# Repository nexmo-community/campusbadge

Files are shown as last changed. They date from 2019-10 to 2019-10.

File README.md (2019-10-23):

# Vonage Campus Developer Conference Badge

Welcome to [Vonage Campus](https://www.vonage.com/campus/)! This repo is dedicated to the software for the Developer Track Conference Badges.

We love all things [#badgelife](https://hackaday.com/tag/badgelife/) and we thought our attendees might enjoy this too :)

Badge owners: check the [wiki](https://github.com/nexmo-community/campusbadge/wiki) for all the information.

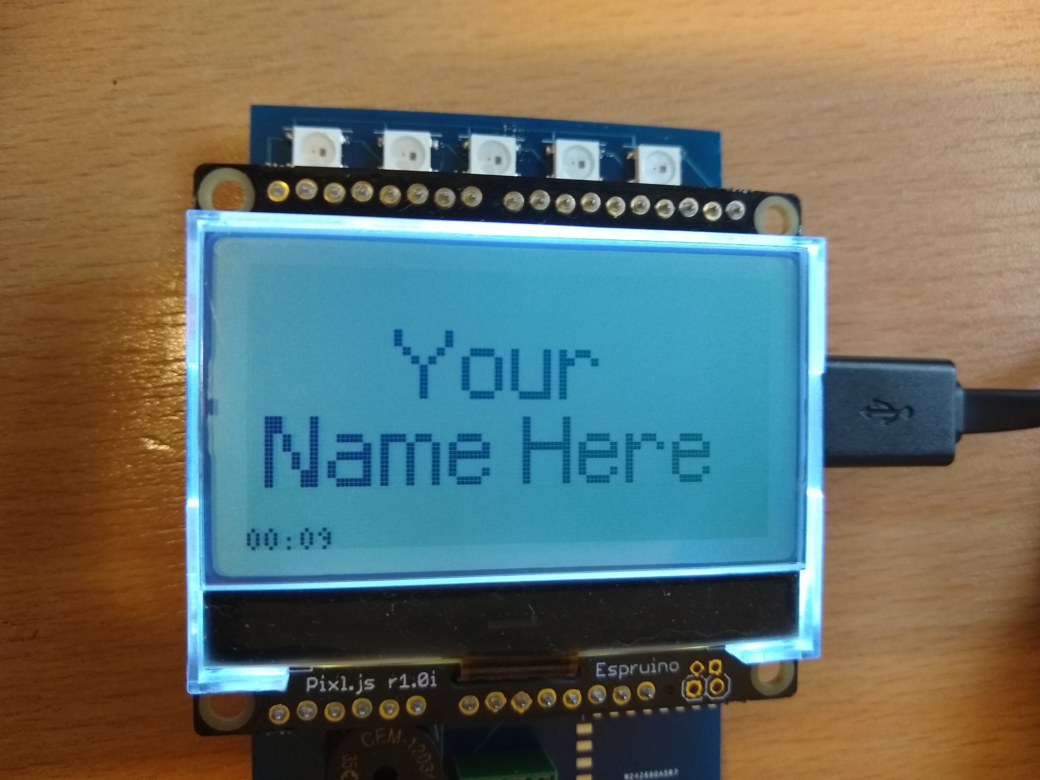
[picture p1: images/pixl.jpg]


## About and Acknowledgements

The Vonage Campus Developer Track Badge is based heavily on the [NodeConfEU Badge from 2018](https://github.com/nearform/nceubadge2018). Many thanks to them for sharing their fun with us :)

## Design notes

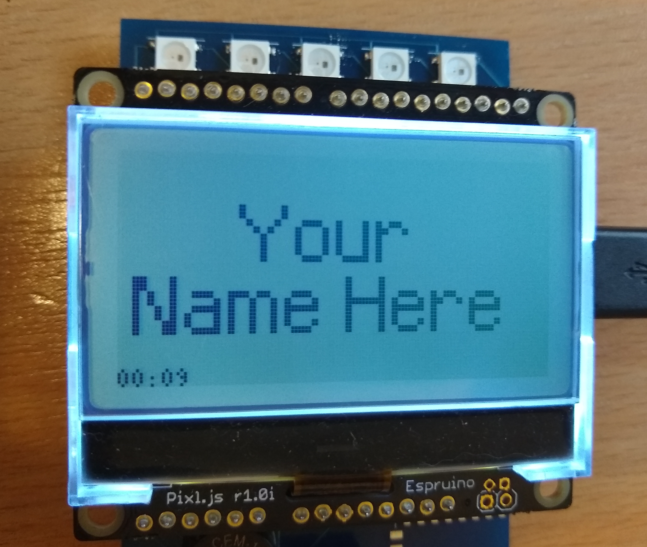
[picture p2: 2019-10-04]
images/your-name-here.jpg

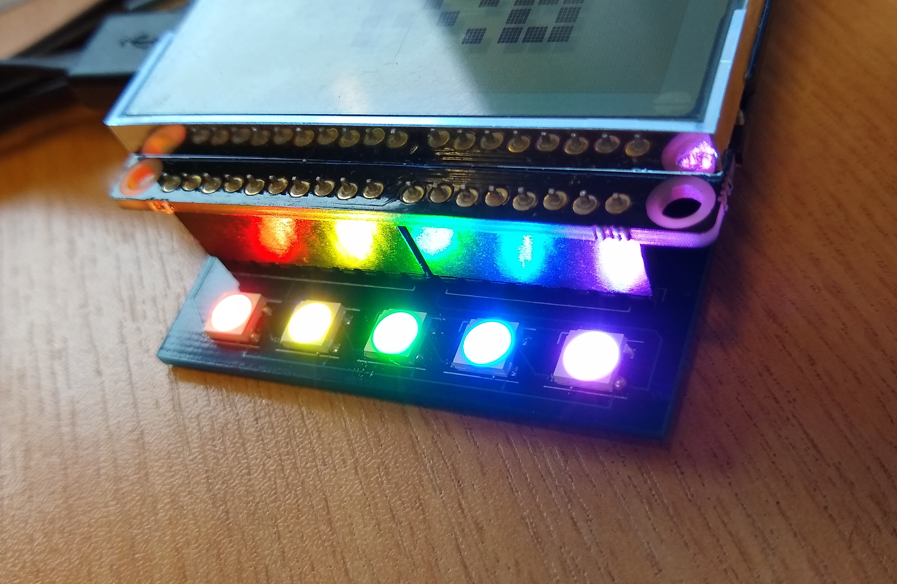
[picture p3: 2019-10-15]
images/pixl-rainbow.jpg

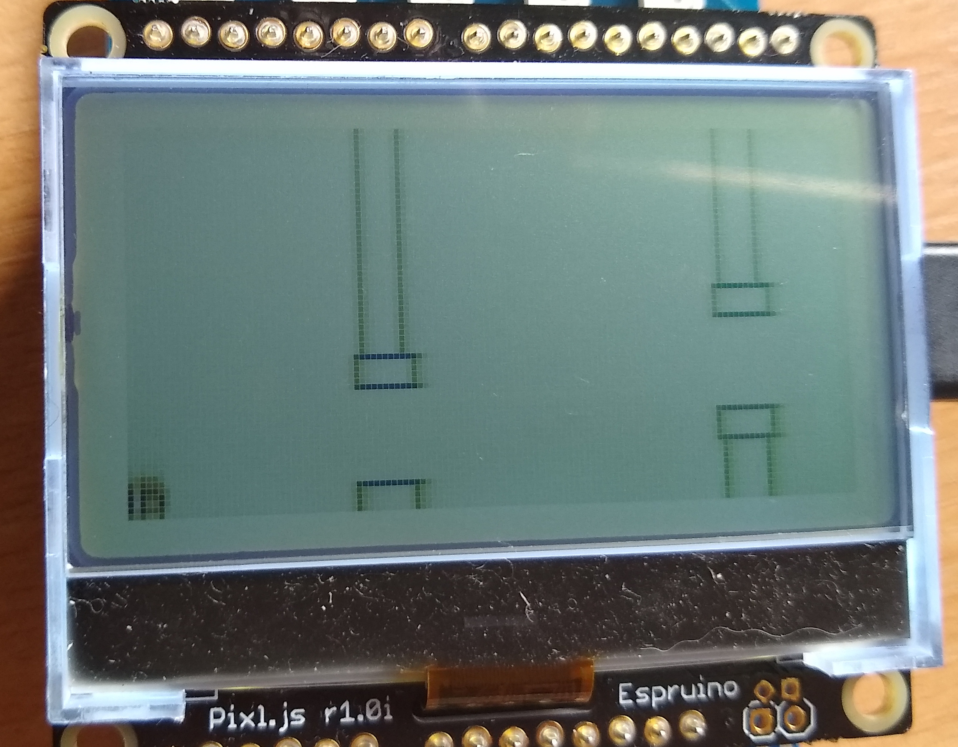
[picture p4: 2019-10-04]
images/flappy.jpg

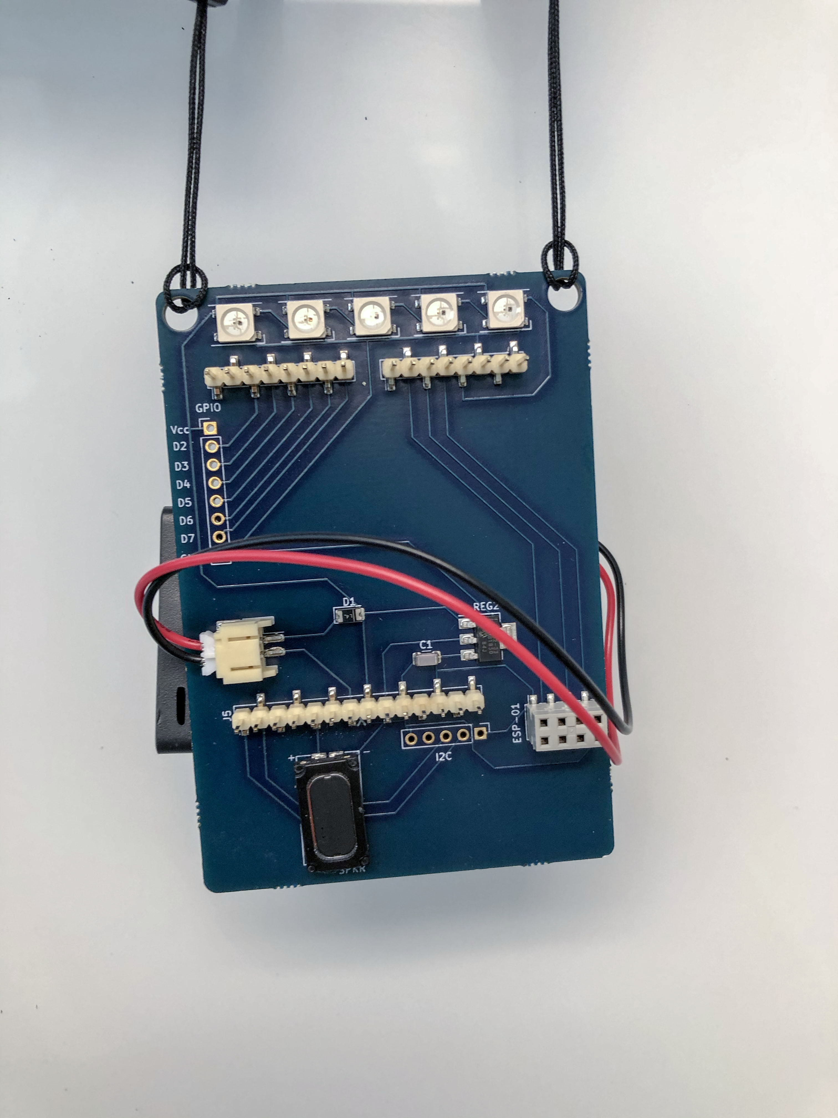
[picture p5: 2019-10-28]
images/board-with-battery.jpg

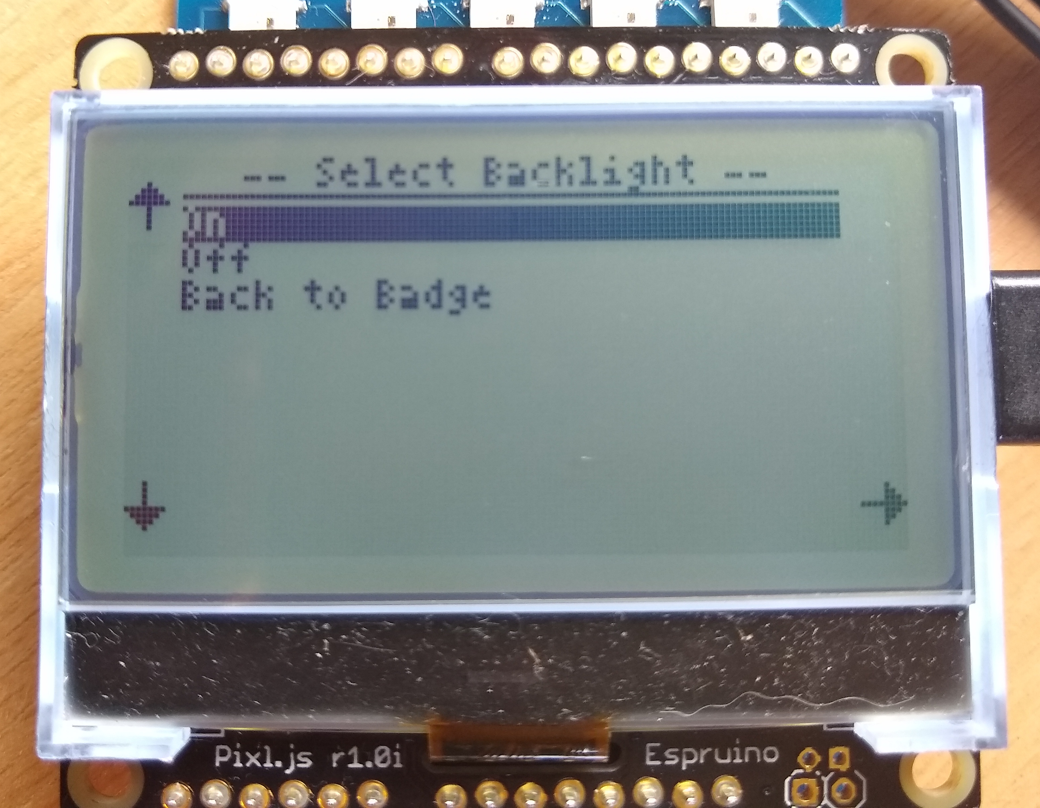
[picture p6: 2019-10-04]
images/backlight-menu.jpg

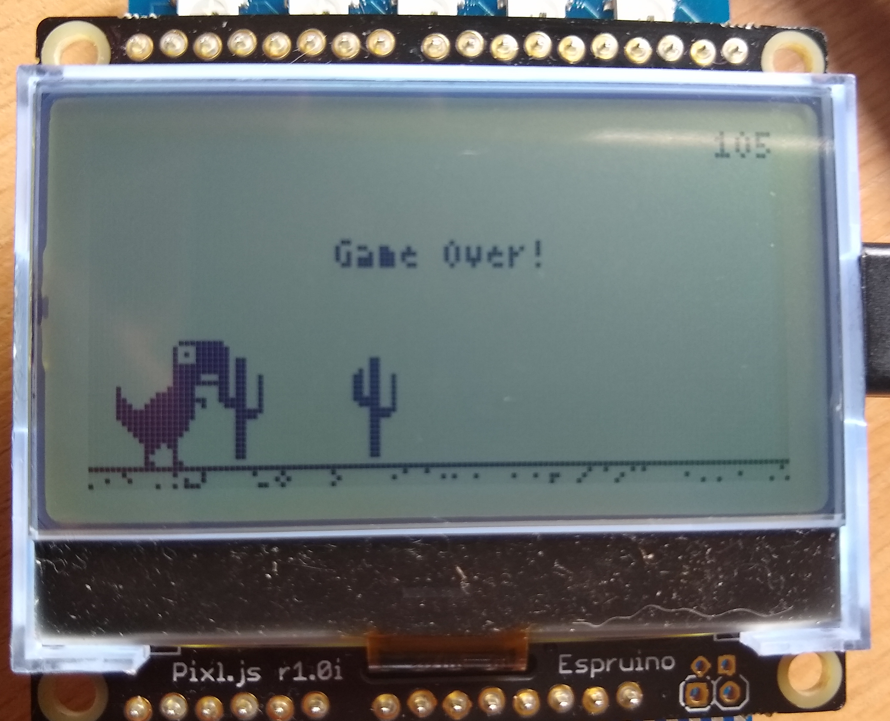
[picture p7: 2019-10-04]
images/trex.jpg

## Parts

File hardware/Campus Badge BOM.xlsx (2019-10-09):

 |  |  | xxxx xxxx xxxxx xxPCS BOM (Sample Bill of Materials)
Item # | *Ref Des | *Qty | Manufacturer | *Mfg Part # | Description / Value | *Package | Type | Your Instructions / Notes
1 | LED | 5 | Adafruit | 1655 | SK6812 RGB LED 5mmx5mm | SK6812 | SMD | 1528-1104-ND
2 | J3 | 1 | Wurth Electronics | 61300811121 | PinHeader_1x08_P2.54mm_Vertical |  | Thru Hole | 732-5321-ND
3 | J4 | 1 | Wurth Electronics | 61301011121 | PinHeader_1x10_P2.54mm_Vertical |  | Thru Hole | 732-2670-ND
4 | J5 | 1 | Wurth Electronics | 61301011121 | PinHeader_1x15_P2.54mm_Vertical |  | Thru Hole | 732-5326-ND‎
5 | J1 | 1 | JST | S2B-PH-SM4-TB(LF)(SN) | CONN HEADER SMD R/A 2POS 2MM |  | SMD | 455-1749-1-ND
6 | REG1 | 1 | Microchip Technology | TC1262-3.3VDBTR | IC REG LIN 3.3V 500MA SOT223-3 | SOT223-5 | SMD | TC1262-3.3VDBTR-ND
7 | SPKR | 1 | CUI Inc | CVS-1508 | SPEAKER 8OHM 300MW TOP PORT 87DB |  | Thru Hole | 102-2498-ND
8 | J2 | 1 | TE Connectivity AMP Connectors | 215308-4 | CONN RCPT 8POS 0.1 TIN PCB |  | Thru Hole | A121790-ND
9 | J6 | 1 | Wurth Electronics | 61300511121 | CONN HEADER VERT 5POS 2.54MM |  | Thru Hole | 732-5318-ND
10 | D1 | 1 | AVX Corporation | SD1206S040S2R0 |  | 1206 (3216) | SMD | 478-7806-1-ND
11 | C1 | 1 | TDK | C3216C0G1H104J160AE | 0.1µF ±5% 50V Ceramic Capacitor C0G, NP0 1206 (3216 Metric) | 1206 (3216) | SMD | 445-C3216C0G1H104J160AECT-ND
Need a quick and accurante quote? Need an efficient production? Please read SMT Ordering Necessary Files & Info in 1 minute. Thank you very much! (https://www.pcbway.com/smt_ordering_guide.html)
Click for Instructions on How to Create a BOM (https://www.pcbway.com/blog/PCB_Assembly/How_to_Build_a_BOM__Bill_Of_Materials_.html)

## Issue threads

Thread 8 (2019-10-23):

Bug on temperature screen

lornajane, 2019-10-23:
When I press menu-down (btn4, bottom left) on the temperature menu, I get a scrambled output.

sammachin, 2019-10-23:
was missing a badge.reset() from the start of the temperature app so would have still been listning for whatever previous handler was set. Fixed in cb00b90 please retest

Closed 2019-10-23.

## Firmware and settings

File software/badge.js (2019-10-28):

Badge = global.Badge || {};
Badge.URL = Badge.URL || "https://static.nexmodev.com/badge.html";
Badge.NAME = Badge.NAME || ["Your", "Name Here"]; // ISO10646-1 codepage
Badge.WIFI_SSID = Badge.WIFI_SSID || "Vonage";
Badge.WIFI_PW = Badge.WIFI_PW || "Events19";
Badge.backlight = false;
// User-defined apps
Badge.apps = Badge.apps || {};
Badge.patterns = Badge.patterns || {};


//Patch for neopixel lib on pixl
var _npwrite = require("neopixel").write;
require("neopixel").write = function(p,d) {
  var n = 0;
  // search for watches on D22
  for (var i=0;i<8;i++)
    if (((peek32(0x40006510+i*4)>>8)&31)==22)
      n = 0x40006510+i*4;
  // if there was one, disable it
  if (n) poke32(n, peek32(n)&~3);
  // do neopixel write
  _npwrite(p,d);
  // re-enable watch
  poke32(0x40025564,0xFFFFFFFF);
  poke32(0x50000758,12);
  if (n) poke32(n, peek32(n)|1);
};

var np =  require("neopixel");

var BTNS = [BTN1, BTN2, BTN3, BTN4];
// --------------------------------------------
// Get Badge back to normal-ish
Badge.reset = () => {
  digitalWrite(D11,0); // disable ESP8266
  Pixl.menu();
  clearInterval();
  clearWatch();
  Bluetooth.removeAllListeners();
  LoopbackB.removeAllListeners();
  g.setRotation(0);
  g.setFontBitmap();
  g.clear();
  g.flip();
  Badge.updateBLE();
};
// --------------------------------------------
// Should the badge be connectable?
Badge.connectable = false;
// --------------------------------------------
Badge.getName = () =>
  NRF.getAddress()
    .substr(-5)
    .replace(":", "");
Badge.updateBLE = () => {
  var adv = {
    showName: Badge.connectable,
    connectable: Badge.connectable,
    interval: Badge.connectable ? 100 : 1000
  };
  NRF.setAdvertising({}, adv);
  NRF.setServices(undefined, { uart: Badge.connectable });
};
// --------------------------------------------
// Fullscreen stuff
Badge.drawCenter = (txt, title, big) => {
  g.clear();
  g.setFontAlign(0, 0);
  if (title) {
    g.fillRect(0, 0, 127, 7);
    g.setColor(0);
    g.drawString(title, 64, 4);
    g.setColor(1);
  }
  var l = txt.split("\n");
  if (big) Badge.setBigFont(g);
  var h = big ? 10 : 6;
  l.forEach((s, i) => g.drawString(s, 64, 34 + (i - (l.length - 1) / 2) * h));
  g.setFontBitmap();
  g.setFontAlign(-1, -1);
  g.flip();
};
// https://raw.githubusercontent.com/Tecate/bitmap-fonts/master/bitmap/dylex/7x13.bdf
// ISO10646-1 codepage
Badge.setBigFont = g => {
  var font = atob(
    "AAAAAAAAA/QAAcAAAHAAAAJAf4CQH+AkAAAMQJIP+CSBGAAAQAUIEYAwBiBCgAgAAG4EiCRA0gBgDIAAOAAAAfAwYgCAAIAjBgfAAACgAgB8AIAKAAABAAgB8AIAEAAAACAOAAAIAEACABAAgAAADAAAAYAwBgDAGAAAAfgQIJkECB+AAAIQIIP8ACABAAAQwQoIkEiBhAAAQgQIJEEiBuAAADACgCQCID/ACAAAeQJEEiCRBHAAAHwFEEiCRAHAAAQAIMEYCwBgAAANwJEEiCRA3AAAOAIkESCKA+AAAGYAAAAgzgAACACgCICCAAAKAFACgBQAoAAAggIgCgAgAABABAAjQSAGAAAA8AhAmQUoL0CKA4AAABwHAMgGQA4ADgAAf4JEEiCRA4gDgAADwCECBBAggQIQAAH+CBBAggQIQDwAAD/BIgkQSIJEECAAB/gkASAJAEAAAAeAQgQIIkESBOAAA/wCABAAgAQB/gAAQIP8ECAAABAAQQIIEH8AAB/gEADACQCECBAAA/wAIAEACABAAA/wMABgAwBgB/gAAf4MABgAMABg/wAADwCECBBAgQgHgAAH+CIBEAiAOAAAB4BCBAggQIQD2AAD/BEAiARgHIACAAAxAkQSIIkESBGAAAgAQAIAH+CABAAgAAAP4ACABAAgAQfwAAHAAcABgAwDgOAAAD4ADgGAMABgAOD4AAAwwEgBgAwAkBhgAAYACAAgAPAIAIAYAAAEGCFBEgkQUIMEAAH/yAJAEAAYADAAYADAAYAAQBIAn/wAAGAMAYADAAYAAAAIAEACABAAgAQAIAAQAEAAAADAKQFICkA+AAD/gIQEICEA8AAAPAIQEICEAkAAAPAIQEICEP+AAAPAKQFICkA0AAAQA/wkASAIAAAAPAISEJCEh/gAD/gIAEACAA+AAAQBPwAAABAAggSfwAA/4AQAYASAQgAAgAf8AAA/AQAIAD4CABAAfAAAPwEACABAAfAAAHgEICEBCAeAAAP+EICEBCAeAAAHgEICEBCA/4AAPwCACABAAQAAAEQFICkBKAiAAAIAfwCEBCABAAAPgAIAEACA/AAAMABgAMAYAwAAAPAAYAYAwAGABgPAAACEAkAMAJAIQAAD5ACQBIAkP8AACEBGAlAUgMQAAAgAQD3iAJAEAAf/AAEASAI94BAAgAAAIAIAEADAAgAQAQAAAFAHwFUCqBBARAAAACAOAAAAQQI/4kASAAAADgAAA4AAAEAAABAAAAQAAEACAH/AgAQAAAFACgH/AoAUAAAEAEAEABAAQAAAGMAYAwBjAAAAwAADEKRDIiiQRIEYAAAIAKAIgAAH4ECCBA/AkQSIIEAACDFChiRSIKEGCAADAAQAAAEAMAAADAAQAwAEAAABADAAQAwAAAAQAcAfAHABAAAAQAIAEACABAAAAQAIAEACABAAgAQAAAgAgAIAIAAACAB4AgAAAPAGADwAAAEQlIKkJKAiAAAIgCgAgAAAeAQgIQDwCkBSAaAAAIQkYKUJSAxAAAYACAQgAOEIAIAYAAAL8AAAeAQgf4EIBIAAATA+gkQSIAEAABBAfAIgEQCIB8BBAAAwAEgBQAeAUASAwAAAffAADCCYhKQjIIYAAEAAABAAAAH4ECCZBSgpQQIH4AAAQBUAqAPAAAAQAUAVAFAEQAAAQAIAEADwAAH4ECC9BUglQQIH4AAIAEACABAAgAQAIAAAAwAkASAGAAAAIgEQPoBEAiAACIBMAqAJAAAEQCoBUAUAAAEAEAAAAAEH8AIACABAfAAQAAGAHgD/hAA/4QAAAA4AcAOAAAAFADAACQD4AEAAAOAIgEQBwAAAEQBQBUAUAEAAA8YAwBkDGGHgAgAAeMAYAwBpjFQBIAAIgFTB2AMgYww8AEAAADACQWIAEAEAAADgOBJAUgBwAHAAABwHAUgSQA4ADgAAA4TgSQJICcABwAAAcJwJICkCOAA4AAAOE4AkASAnAAcAAAHDcCSBJAbgAOAAADgGANAIgH+CRBAgAAHgEIECSBxAgQgAAH8SSFJAkgQQAAH8CSFJEkgQQAAH8KSJJCkgQQAAH8KSBJCkgQQAAEET+FBAAAQQv4kEAAFBE/hQQAAUED+FBAAACAP4EkCSBBARAHAAAH8KAIwCGCAwP4AAA4AiEghQQEQBwAAAcARBQRIICIA4AAAOBIhIIkEJEAcAAAHAkQkEKCIiAOAAADgSICCBBCRAHAAACIAoAIAKAIgAAD0CECNBYgQgXgAAD8ABEAhAQAIH4AAB+AAhARAIAED8AAA/BARAIgEICB+AAAfggIAEACEBA/AAAMABAAQEHEEAEAMAAAH+AkASAJADAAAABD/CQhIQkINEAcAAADAKQlIKkA+AAADAKQVISkA+AAADAqQlIKkA+AAADAqQlIKkI+AAADAqQFIKkA+AAADBKRVISkA+AAADAKQFIB8BSApANAAADwCEhDghAJAAADwSkFSApANAAADwKkJSApANAAADwKkJSCpANAAADwKkBSCpANAAAkAL8AACgCfgAAUAT8EAAACQAPwgAAAAcERCogkQvwAAF+EgBQBIAD4AAA8EhBQgIQDwAAA8AhBQhIQDwAAA8ChCQgoQDwAAA8ChCQgoQjwAAA8ChAQgoQDwAAAQAIAVACABAAAA9AjAWgMQLwAAB8EBBAgAQH4AAB8CBCAgAQH4AAB8CBCAggQH4AAB8CBAAggQH4AAB8ABJAlASH+AAH/ghAQgIQDwAAB8CBIAkgSH+AAA"
  );
  var widths = atob(
    "AwIEBgYIBwIEBAYGAwYCBgYGBgYHBgYGBgYCAwUGBQYIBwcHBwcGBwcEBgcGBwcHBgcHBwgHBwgHCAcEBgQGCAMGBgYGBgYGBgMFBgMIBgYGBgYGBgYGCAYGBgYCBggABwADBgQGBgYGBwcECAAHAAADAwUFBgYIBQgGBAgABggAAgYGCAgCBgQIBQYFAAgIBQYFBQMIBwQDBAUGBwcIBgcHBwcHBwgHBgYGBgQEBAQIBwcHBwcHBgcHBwcHCAYIBgYGBgYGCAYGBgYGAwMEBAYGBgYGBgYGBgYGBgYGBgY="
  );
  g.setFontCustom(font, 32, widths, 13);
};
// align=-1=left,0,1=right
Badge.drawStringDbl = (txt, px, py, h, align) => {
  var g2 = Graphics.createArrayBuffer(128, h, 2, { msb: true });
  Badge.setBigFont(g2);
  var w = g2.stringWidth(txt);
  var c = (w + 3) >> 2;
  g2.drawString(txt);
  if (w > 55) {
    // too wide - use 1x
    var img = g2.asImage();
    g.transparent = 0;
    px -= ((align + 1) * w) / 2;
    g.drawImage(img, px, py + 2);
    return;
  }
  px -= (align + 1) * w;
  var img = {
    width: w * 2,
    height: 1,
    transparent: 0,
    buffer: new ArrayBuffer(c)
  };
  var a = new Uint8Array(img.buffer);
  for (var y = 0; y < h; y++) {
    a.set(new Uint8Array(g2.buffer, 32 * y, c));
    g.drawImage(img, px, py + y * 2);
    g.drawImage(img, px, py + 1 + y * 2);
  }
};
// --------------------------------------------
// Main menu
Badge.menu = () => {
  function wait(cb) {
    m = { move: cb, select: cb };
  }
  var mainmenu = {
    "": { title: "-- Campus Badge --" },
    "Back to Badge": Badge.badge,
    "Toggle Backlight": () => {
      Badge.backlight = !Badge.backlight; 
      LED1.write(Badge.backlight);
    },
    "Make Connectable": () => {
      Badge.drawCenter(`-- Now Connectable --

You can connect to this badge
with a BLE capable device. Go to
espruino.com/ide on a Web BLE
capable browser to start coding!
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

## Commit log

2019-10-04 Remove low battery warning
2019-10-08 Added neopixel fix and fixed alert/info
    [badge.js]
2019-10-09 Hardware Files
    [Campus Badge BOM.xlsx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]
2019-10-13 update NR workshop
    [PixlVBoard-B_Cu.gbr, PixlVBoard-B_Fab.gbr, PixlVBoard-B_Mask.gbr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]
2019-10-15 Sounds - with a write error
    [badge.js]
2019-10-15 Better animation timer logic
2019-10-15 Update badge.js
    switched to tinyMQTT, removed time, some small optimisations. now seems to run fine on badge
2019-10-24 added name to lights
    Added an option to display the name from the lights menu so the animation keeps going, pressing a button takes you back to the lights menu and back to badge still exits and stops the animations
2019-10-24 Update badge.js
    Added default WiFi details for workshop and also explicitly turning off wifi pin on Badge.reset()
    [badge.js]
2019-10-28 Adding video on assembling badge
